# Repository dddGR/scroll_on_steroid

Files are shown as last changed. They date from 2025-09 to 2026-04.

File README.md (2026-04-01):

# Scroll On Steroid

## Table of Contents

- [Overview](#overview)
- [Features](#features)
- [Hardware Requirements](#hardware-requirements)
- [Build guide](#build-guide)
- [Firmware build](#firmware-build)
- [Usage](#usage)
- [Contributing](#contributing)

## Overview

This project is a scroll device that emulates mouse scrolling with enhanced smoothness, utilizing resolution multiplier.

It connects via Bluetooth Low Energy (BLE) and incorporates a touch sensor for user interaction. Users can easily adjust scrolling speed and direction (horizontal/vertical) through a touch button interface.

The device is built on the ESP32-C3/S3 microcontroller and an AS5600 magnetic encoder. This project is developed using the ESP-IDF framework and is entirely written in C.

> ***Only tested on Windows/Linux. Not working on Android. Not yet tested on Mac OS or IOS***

## Features

- **Smooth Scrolling**: Utilizes a resolution multiplier for enhanced scrolling experience.

- **Bluetooth BLE Connectivity**: Wireless connection.

- **Touch Sensor**: Detects user interactions to eliminate false movement.  
User can change scrolling speed or direction via touch interface.

- **Long Battery Life**: Built-in 2000mAh battery for extended use.

- **Easy Assembly**: All components are off-the-shelf parts for straightforward assembly.

## Hardware Requirements

- ESP32-S3/C3 micro sized board
- Magnetic encoder: AS5600
- Touch sensor module: TP223 *(for C3 only)*
- 6809-2RS bearing
- 10345 2000mAh lipo battery
- LX-LBC3 lipo charging module
- SW-200D vibration switch *(for C3 only)*
- MSK12C02 switch *(*optinal)*
- Other components (screw, wire...)

## Build guide

The complete build guide contain in this [Document](https://docs.google.com/presentation/d/1pcG5sJjjT5bdXRbsl7uQMGZX0v1NefzA5OYjOddV2WQ).

## Firmware build

For convenient, a precompiled `firmware_xx.bin` is provided for direct flashing onto the microcontroller (MCU). However, this file contains only the default configuration and is intended for use with the exact hardware specified in the instruction document. For custom configurations, users will need to modify the config, via menuconfig (recommended) or directly in the `user_config.h` file and recompile it themselves.

---------------------------------------------------------------------
The following steps are intended for those who have never used ESP-IDF before. If you are already familiar with ESP-IDF and have existing projects, you can simply take the source files and compile them.

1. **Install the ESP-IDF Framework**

   It is recommended to use Visual Studio Code (VSCode) along with the ESP-IDF extension. Espressif provides detailed documentation on  [installing and using ESP-IDF](https://github.com/espressif/vscode-esp-idf-extension/blob/master/README.md).

2. **Try a Test Build (Optional but Recommended)**

   If you are not familiar with ESP-IDF, it is advisable to build and flash an example sketch from the ESP-IDF example library. This will also help ensure that your board is functioning correctly. Espressif has a very detail [guide](https://docs.espressif.com/projects/vscode-esp-idf-extension/en/latest/startproject.html) for this process.  
   > **Note:** I recommend trying to build the `hello_world` example first, as the `blink` example's default configuration may not work for all board variants.

3. **Create Your ESP-IDF Project**

   Git clone the source code and open it in VSCode (select "Open Folder"). ESP-IDF will notify you if any files are missing; you can ignore this. Open the `ESP-IDF terminal` and type:

   ```bash
   idf.py reconfigure
   ```

   This command will reconfigure your project folder. If any files are missing or settings have not been applied, this will resolve those issues.  
   In fact, whenever I make changes (e.g., editing `CMakeLists` or adding new files or components), I often encounter errors. Usually, cleaning the build and running `reconfigure` again resolves these issues.

   > **Note:** You can open the `ESP-IDF terminal` using a shortcut in the bottom bar or by pressing `Ctrl+Shift+P` and typing `Open ESP-IDF terminal`. This terminal is different from the standard VSCode terminal (usually PowerShell) and includes all the necessary commands, making it much easier to use. If you encounter an error stating that a file is not found or a command is unrecognized, you are likely not using the ESP-IDF terminal.

4. **Select Your MCU Target**

   In the bottom bar, locate the IDF-TARGET box (which will initially display "esp32") and change it to your specific board (S3 or C3). If prompted for a path list, simply choose the first option. Wait for the configuration to complete.

   > **Note:** When you have an IDF terminal open and use the icon in the bottom bar to change the IDF-TARGET, the terminal will not automatically switch to the new board. Any commands run in that terminal will result in a target mismatch error. Close the terminal and open a new one to resolve this issue.

5. **Build and Flash the Project**

   If everything is set up correctly, click the build wrench icon labeled `Build Project` or use the command:

   ```bash
   idf.py build
   ```

   If the build is successful, you can now flash the firmware to your board. Connect your board and set the port to the correct one.

   > If you have only one board connected, it will display only that one.

   Set the flash method to UART (the star icon) and click the flash icon labeled `Flash Device` or use the command:

   ```bash
   idf.py flash
   ```

6. **Complete the Flashing Process**

   Wait for the flashing process to complete, and you are done.

## Usage

- Connect your device via Bluetooth. When prompted for passcode confirmation, simply click OK (or Pair).
- The device features two built-in scroll modes that can be switched with a double press:

> - **Vertical**: Functions like a regular mouse scroll.
> - **Horizontal**: Scrolls in the horizontal direction.

- Additionally, there are two speed settings, fast and slow, which can be changed with a triple press.

> **Note:**
>
> - Only two button functions are implemented for simplicity.
> - Single press is not used for button input to eliminate false button presses during normal usage.
> - Buttons only register when the device is in idle mode. This means that if you want to change settings (e.g., scroll direction) while using the device, you need to lift your finger for about 0.5 seconds before double pressing (or triple pressing).

## Contributing

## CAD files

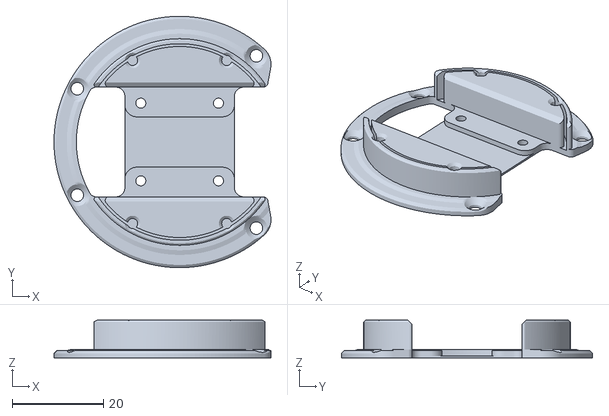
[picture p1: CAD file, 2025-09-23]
hardware/sos_lite_inner_upper.stl
47.5 x 55.0 x 8.30

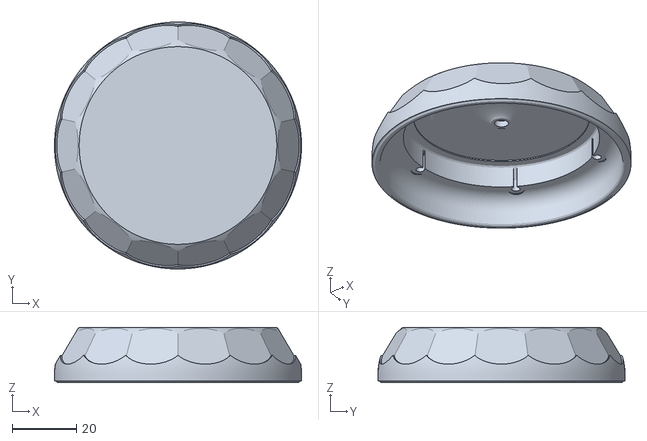
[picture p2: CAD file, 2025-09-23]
hardware/sos_lite_outer_shell.stl
77.0 x 77.0 x 17.2

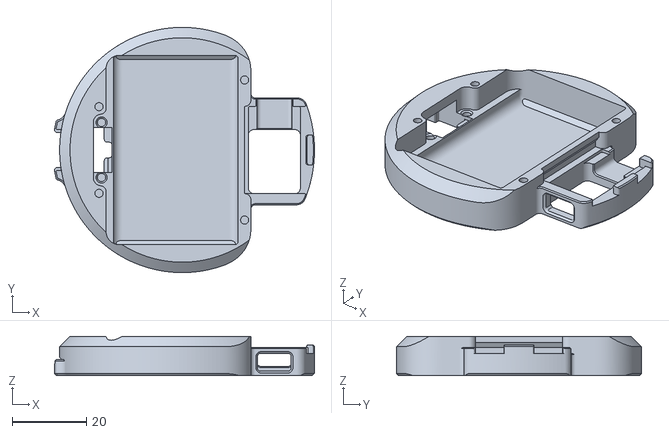
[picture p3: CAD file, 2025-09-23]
hardware/sos_lite_inner_bottom.stl
70.0 x 66.0 x 10.6

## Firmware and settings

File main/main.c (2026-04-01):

#include "HID_bluedroid.h"
#include "driver/gpio.h"
#include "driver/i2c_master.h"
#include "driver/uart.h"
#include "esp_as5600.h"
#include "esp_check.h"
#include "esp_sleep.h"
#include "freertos/FreeRTOS.h"  // IWYU pragma: export
#include "freertos/task.h"      // IWYU pragma: export
#include "sdkconfig.h"
#include "touch_Button.h"
#include "user_Config.h"
#include "user_Config_priv.h"
#include "user_HID_Descriptor.h"

// clang-format off
/* This two variables are store in RTC memory to reuse when device is go to sleep and reboot */
RTC_DATA_ATTR static volatile ScrollSpeedDiv_t g_scroll_div = SPEED_LOW;
RTC_DATA_ATTR static volatile ScrollDirection_t g_scroll_dir = SCROLL_VERTICAL;
// clang-format on

static TaskHandle_t hdl_scroll_task;
/* this is mainly for printing log, can be removed if not needed */
/* ------------------------------- */
static TaskHandle_t hdl_button_task;
#if !CONFIG_USE_TOUCH_BUILTIN
static TaskHandle_t hdl_touch_task;
#endif
/* ------------------------------- */

/* hanle all the events */
static EventGroupHandle_t g_xEventGroup;

#if !CONFIG_USE_TOUCH_BUILTIN
/**
* @brief: The external touch is connected to a GPIO pin and functions as a button. 
* This task is responsible for listening to the input in polling mode and 
* updating the event group bit accordingly. The "lastbits" variable is used 
* to ensure that the bit changes only when necessary. 
*/
void task_TouchScan(void* pvParameter) {
    const char* TAG = "[TOUCH]";
    ESP_LOGI(TAG, "Initializing Touch...");
    ESP_ERROR_CHECK(init_TouchExternal(TAG, CONFIG_PIN_TOUCH_SENSOR));

    EventGroupHandle_t xEventGroup = (EventGroupHandle_t)pvParameter;
    EventBits_t lastbits           = xEventGroupGetBits(xEventGroup);
    EventBits_t currbits;
    TickType_t _xLastWakeTime = xTaskGetTickCount();

    for ( ;; ) {
        currbits = (gpio_get_level(CONFIG_PIN_TOUCH_SENSOR)) ? BUTTON_PRESSED
                                                             : BUTTON_RELEASED;

        if ( currbits & lastbits ) {
            goto end_loop;
        }

        xEventGroupClearBits(xEventGroup, BUTTON_PRESSED | BUTTON_RELEASED);
        lastbits = xEventGroupSetBits(xEventGroup, currbits);

end_loop:
        /* ~100hz */
        xTaskDelayUntil(&_xLastWakeTime, pdMS_TO_TICKS(10));
    }

    /* safe guard */
    vTaskDelete(NULL);
}
#endif

#if CONFIG_USE_TOUCH_BUTTON
/**
* @brief: This task listens for button presses and handles them only when 
* the device is idle and Bluetooth is connected. It has two main functions: 
* 
*   1. If the user double presses the button, it changes the scroll direction 
*    (Horizontal/Vertical).
*   2. If the user triple presses the button, it changes the scroll speed 
*    (High/Low).
* 
* These actions modify a global variable that will be utilized in the 
* {task_MouseScroll}. Single presses are not recognized to prevent 
* false button triggers. 
*/
static void task_Button(void* pvParameter) {
    const char* TAG = "[BUTTON]";

    for ( ;; ) {
        xEventGroupWaitBits(g_xEventGroup,
                            DEVICE_IDLE | BLE_CONNECTED,
                            pdFALSE,
                            pdTRUE,
                            portMAX_DELAY);

        switch ( getButtonPressState(g_xEventGroup, hdl_scroll_task) ) {
            case B_PRESS_2: {
                g_scroll_dir = (g_scroll_dir == SCROLL_HORIZONTAL)
                    ? SCROLL_VERTICAL
                    : SCROLL_HORIZONTAL;
                ESP_LOGI(TAG, "[double pressed] - Change scroll direction.");
            } break;
            case B_PRESS_3: {
                g_scroll_div = (g_scroll_div == SPEED_HIGH) ? SPEED_LOW
                                                            : SPEED_HIGH;
                ESP_LOGI(TAG,
                         "[triple pressed] - Change scroll speed to %s",
                         (g_scroll_div == 1) ? "HIGH" : "LOW");
            } break;
            case B_PRESS_NONE: {
                xEventGroupWaitBits(g_xEventGroup,
                                    DEVICE_ACTIVE,
                                    pdFALSE,
                                    pdTRUE,
                                    portMAX_DELAY);
            } break;
            default:
                break;
        }
    }
    /* safe guard */
    vTaskDelete(NULL);
}
#endif  // CONFIG_USE_TOUCH_BUTTON

static esp_err_t init_Hardware(const char* TAG,
                               i2c_master_bus_handle_t* p_i2c_bus_handle,
                               i2c_master_dev_handle_t* p_i2c_dev_handle,
                               esp_hidd_dev_t** p_hid_dev) {
    ESP_LOGI(TAG, "Initializing BLE.....");
    xEventGroupSetBits(g_xEventGroup, BLE_DISCONNECTED);

    esp_hid_raw_report_map_t ble_report_maps[] = {
        {.data = scrollDescriptor_hiRes,
         .len  = sizeof(scrollDescriptor_hiRes)}};

    const esp_hid_device_config_t ble_hid_config = {
        .vendor_id         = 0x16C0,
        .product_id        = 0x05DF,
        .version           = 0x0100,
        .device_name       = DEVICE_NAME,
        .manufacturer_name = DEVICE_MANUFACTURER,
        .serial_number     = DEVICE_SERIAL,
        .report_maps       = ble_report_maps,
        .report_maps_len   = 1};

    ESP_ERROR_CHECK_WITHOUT_ABORT(hidDevInit(p_hid_dev, &ble_hid_config));

    ESP_LOGI(TAG, "Initializing Magnetic Sensor.....");
    gpio_config_t pin_config = {.pin_bit_mask = BIT(CONFIG_PIN_SENSOR_POWER),
                                .mode         = GPIO_MODE_OUTPUT,
                                .pull_up_en   = GPIO_PULLUP_DISABLE,
                                .pull_down_en = GPIO_PULLDOWN_DISABLE,
                                .intr_type    = GPIO_INTR_DISABLE};
    ESP_RETURN_ON_ERROR(gpio_config(&pin_config),
                        TAG,
                        "failed to configure power pin..");
    ESP_RETURN_ON_ERROR(gpio_set_level(CONFIG_PIN_SENSOR_POWER, 1),
                        TAG,
                        "failed to turn on power..");

    vTaskDelay(pdMS_TO_TICKS(50));

    i2c_master_bus_config_t bus_config = {
        .i2c_port                     = I2C_NUM_0,
        .sda_io_num                   = CONFIG_PIN_SENSOR_SDA,
        .scl_io_num                   = CONFIG_PIN_SENSOR_SCL,
        .clk_source                   = I2C_CLK_SRC_DEFAULT,
        .glitch_ignore_cnt            = 7,
        .flags.enable_internal_pullup = true,
    };

    i2c_device_config_t dev_config = {
        .dev_addr_length = I2C_ADDR_BIT_LEN_7,
        .device_address  = AS5600_DEFAULT_ADDRESS,
        .scl_speed_hz    = 100000UL,
    };

    ESP_RETURN_ON_ERROR(as5600_init(p_i2c_bus_handle,
                                    &bus_config,
                                    p_i2c_dev_handle,
                                    &dev_config),
                        TAG,
                        "failed to init as5600");

    /**
     * @brief: If the SoC has a built-in touch sensor, it will be initialized. 
     * Otherwise, a task will be created to listen for input from the external 
     * touch sensor. The button task will utilize data from the touch sensor 
     * to execute the corresponding button actions.  
     */
#if CONFIG_USE_TOUCH_BUILTIN
    ESP_LOGI(TAG, "Initializing Internal TouchSensor...");
    ESP_ERROR_CHECK(init_TouchBuitin(TAG, CONFIG_TOUCH_PAD_ID, g_xEventGroup));
#else
    xTaskCreatePinnedToCore(&task_TouchScan,
                            "task_TouchScan",
                            2560,
                            (void*)g_xEventGroup,
                            6,
                            &hdl_touch_task,
                            (BaseType_t)APP_CORE_ID);
    vTaskDelay(pdMS_TO_TICKS(100));
#endif  // CONFIG_USE_TOUCH_BUILTIN

#if CONFIG_USE_TOUCH_BUTTON
    xTaskCreatePinnedToCore(&task_Button,
                            "task_Button",
                            3072,
                            NULL,
                            5,
                            &hdl_button_task,
                            (BaseType_t)APP_CORE_ID);
#endif  // CONFIG_USE_TOUCH_BUTTON

    return ESP_OK;
}

/**
* @brief: The {task_MouseScroll} is responsible for reading the encoder and
* sending the scroll data to the HID device via the Bluetooth interface. This
* task also determines the idle and active states of the device. 
*/
static void task_MouseScroll(void* pvParameter) {
    const char* TAG = "[SCROLL]";

    static uint8_t counter_to_idle = 0;
    static uint16_t prev_angle     = 0;
    static uint16_t curr_angle     = 0;
    static EventBits_t bits;
    static i2c_master_bus_handle_t i2c_bus_hdl;
    static i2c_master_dev_handle_t encoder_hdl;
    static esp_hidd_dev_t* p_hid_device;
    ESP_ERROR_CHECK(
        init_Hardware(TAG, &i2c_bus_hdl, &encoder_hdl, &p_hid_device));

    TickType_t xLastWakeTime = xTaskGetTickCount();

    xEventGroupSetBits(g_xEventGroup,
                       DEVICE_IDLE
    /* if no touch interface is used, then device is set to always active */
#if !CONFIG_USE_TOUCH_BUTTON
                           | BUTTON_PRESSED
#endif
    );
    xEventGroupWaitBits(g_xEventGroup,
                        BLE_CONNECTED,
                        pdFALSE,
                        pdFALSE,
                        portMAX_DELAY);

    for ( ;; ) {
        /** @brief:: This is the checkpoint to wait for the device to be active. 
          * If the device is in an active state (or button is pressed) but the
          * "device idle" bit is set, it indicates a transition from idle to active.
          * The next if statement will clear the idle bit while simultaneously 
          * retrieving the current angle of the encoder. This step is crucial 
          * to prevent any changes in angle caused by the magnet spinning 
          * while the device is idle. 
          * 
          * The remainder of the loop involves reading the angle, calculating 
          * the delta, and sending data to the HID device.
          */
        bits = xEventGroupWaitBits(g_xEventGroup,
                                   DEVICE_ACTIVE | BUTTON_PRESSED,
                                   pdFALSE,
                                   pdFALSE,
                                   portMAX_DELAY);
        if ( bits & DEVICE_IDLE ) {
            ESP_LOGI(TAG, "Active state...");
            as5600_get_raw_angle(encoder_hdl, &curr_angle);
            prev_angle = curr_angle;
            xEventGroupClearBits(g_xEventGroup, DEVICE_IDLE);
            xEventGroupSetBits(g_xEventGroup, DEVICE_ACTIVE);
        }

        as5600_get_raw_angle(encoder_hdl, &curr_angle);
        const int16_t delta_angle = (curr_angle
                                     - prev_angle /*  - curr_angle */);

        ESP_LOGD(TAG,
                 "Current angle: %d -- Angle delta: %d",
                 curr_angle,
                 delta_angle);

        /**
         * @brief: When the delta is smaller than the set threshold, it is assumed that 
         * the device is not active. This helps to filter out noise from the encoder. 
         * The "counter_to_idle" variable counts the number of loops in which the 
         * device remains in this state. 
         * 
         * The "prev_angle" is updated at the end of the loop to account for cases 
         * where the user is scrolling at a very slow speed. Over multiple loops, 
         * the accumulated delta angle may eventually trigger scrolling and clear
         * the "counter_to_idle".
         * 
         * However, if the "counter_to_idle" reaches a certain threshold and the 
         * user is not interacting with the device, it will be set to idle state. 
         */
        if ( abs(delta_angle) < CONFIG_SENSOR_NOISE_THRESHOLD ) {
            bits = xEventGroupWaitBits(g_xEventGroup,
                                       BUTTON_PRESSED,
                                       pdFALSE,
                                       pdTRUE,
                                       0);

            if ( ~bits & BUTTON_PRESSED && ++counter_to_idle > 50 ) {
                /* about 500ms with 100hz polling rate */
                ESP_LOGI(TAG, "Entering idle state...");
                xEventGroupClearBits(g_xEventGroup, DEVICE_ACTIVE);
                xEventGroupSetBits(g_xEventGroup, DEVICE_IDLE);
                counter_to_idle = 0;
            }
            goto end_loop;
        } else if ( counter_to_idle > 0 ) {
            counter_to_idle = 0;
        }

        /* in normal use case, the `delta_angle` always stay bellow 100,
         * so a value `128` here to filter out some cases sensor read value
         * jump up and down randomly (noise maybe).  */
        if ( abs(delta_angle) < 128 ) {
            int8_t scroll_val = (int8_t)delta_angle / (int8_t)g_scroll_div;
            switch ( g_scroll_dir ) {
                case SCROLL_VERTICAL: {
                    sendScroll(p_hid_device, -scroll_val, 0);
                } break;
                case SCROLL_HORIZONTAL: {
                    sendScroll(p_hid_device, 0, scroll_val);
                } break;
            }
        }

        prev_angle = curr_angle;

end_loop:
        /* cap at about ~100hz polling rate */
        xTaskDelayUntil(&xLastWakeTime, pdMS_TO_TICKS(10));
    }
}

/* BLE HID CALLBACK */
/* -------------------------------------------------------------------- */
void do_when_ble_hid_connect(void) {
    while ( !hdl_scroll_task ) {
        vTaskDelay(pdMS_TO_TICKS(100));
    }

    xEventGroupClearBits(g_xEventGroup, BLE_CONNECTED | BLE_DISCONNECTED);
    xEventGroupSetBits(g_xEventGroup, BLE_CONNECTED);
    vTaskResume(hdl_scroll_task);
}

void do_when_ble_hid_disconnect(void) {
    if ( !hdl_scroll_task ) {
        goto end;
    }

    vTaskSuspend(hdl_scroll_task);
end:
    xEventGroupClearBits(g_xEventGroup, BLE_CONNECTED | BLE_DISCONNECTED);
    xEventGroupSetBits(g_xEventGroup, BLE_DISCONNECTED);
}

void do_when_ble_hid_stop(void) {
    /* nothing for now */
}

/* -------------------------------------------------------------------- */

static void esp_pre_sleep_config(const char* TAG) {
#if CONFIG_TOUCH_TO_WAKEUP
    ESP_ERROR_CHECK_WITHOUT_ABORT(regTouchWakeup(TAG));
#endif

#if CONFIG_SHAKE_TO_WAKEUP
    const gpio_config_t config = {.pin_bit_mask = BIT(CONFIG_PIN_WAKEUP),
                                  .mode         = GPIO_MODE_INPUT,
                                  .pull_up_en   = GPIO_PULLUP_DISABLE,
                                  .pull_down_en = GPIO_PULLDOWN_ENABLE,
                                  .intr_type    = GPIO_INTR_DISABLE};

    ESP_ERROR_CHECK_WITHOUT_ABORT(gpio_config(&config));
    ESP_ERROR_CHECK_WITHOUT_ABORT(
        esp_sleep_enable_gpio_wakeup_on_hp_periph_powerdown(
            BIT(CONFIG_PIN_WAKEUP),
            ESP_GPIO_WAKEUP_GPIO_HIGH));
#endif

    ESP_ERROR_CHECK_WITHOUT_ABORT(gpio_set_level(CONFIG_PIN_SENSOR_POWER, 0));

    vTaskDelay(pdMS_TO_TICKS(100));
}

/* ===================================================== */
/* MAIN ================================================ */
void app_main(void) {
    const char* MTAG = "[MAIN]";

#if CONFIG_SHAKE_TO_WAKEUP
    ESP_ERROR_CHECK_WITHOUT_ABORT(gpio_reset_pin(CONFIG_PIN_WAKEUP));
#endif
    g_xEventGroup = xEventGroupCreate();

    xTaskCreatePinnedToCore(&task_MouseScroll,
                            "task_MouseScroll",
                            3584,
                            NULL,
                            5,
                            &hdl_scroll_task,
                            (BaseType_t)APP_CORE_ID);

    /* everything will be config in `task_MouseScroll`,
     * main task now will wait 5 seconds (magic number),
     * and then continue to handle sleeping task. */
    vTaskDelay(pdMS_TO_TICKS(1000 * 5));

    /** MAIN also control sleep function */
    EventBits_t bits;
    for ( ;; ) {
#if CONFIG_USE_TOUCH_BUTTON
        /**
         * @note: The main strategy is to wait for the device to enter an idle state, 
         * after which one of two scenarios will occur: 
         * 
         * 1. If BLE is not connected, the device will wait for 30 seconds before 
         *    going to sleep (if BLE remains disconnected).
         * 2. If BLE is connected, the device will wait for 10 minutes (this duration 
         *    can be adjusted in config.h or menuconfig). If the device does not exit 
         *    the idle state during this time, it will go to sleep; otherwise, the 
         *    loop will continue. 
         */
        xEventGroupWaitBits(g_xEventGroup,
                            DEVICE_IDLE,
                            pdFALSE,
                            pdTRUE,
                            portMAX_DELAY);

        bits = xEventGroupWaitBits(
            g_xEventGroup,
            DEVICE_ACTIVE | BLE_DISCONNECTED,
            pdFALSE,
            pdFALSE,
            pdMS_TO_TICKS(1000 * 60 * CONFIG_IDLE_TIME_BEFORE_SLEEP));

        if ( bits & DEVICE_ACTIVE ) {
            continue;
        }

        if ( bits & BLE_DISCONNECTED ) {
            ESP_LOGW(MTAG,
                     "BLE not connected, wait 30 seconds until go to sleep.");
            bits = xEventGroupWaitBits(g_xEventGroup,
                                       DEVICE_ACTIVE | BLE_CONNECTED,
                                       pdFALSE,
                                       pdFALSE,
                                       pdMS_TO_TICKS(1000 * 30));

            if ( bits & BLE_CONNECTED || bits & DEVICE_ACTIVE ) {
                continue;
            }
        }
#else
        /**
         * @note: If a touch sensor is not used, the device is set to remain always active. 
         * In this case, the only condition for determining when to go to sleep is 
         * checking for BLE disconnection. This is maybe not the best strategy. 
         */
        bits = xEventGroupWaitBits(g_xEventGroup,
                                   BLE_DISCONNECTED,
                                   pdFALSE,
                                   pdTRUE,
                                   portMAX_DELAY);

        ESP_LOGW(MTAG, "BLE not connected, wait 30 seconds until go to sleep.");
        bits = xEventGroupWaitBits(g_xEventGroup,
                                   BLE_CONNECTED,
                                   pdFALSE,
                                   pdTRUE,
                                   pdMS_TO_TICKS(1000 * 30));

        if ( bits & BLE_CONNECTED ) {
            continue;
        }
#endif  // CONFIG_USE_TOUCH_BUTTON

        ESP_LOGW(MTAG, "Entering sleep mode.....");
        esp_pre_sleep_config(MTAG);

        /* Some log for testing */
        ESP_LOGW(MTAG, "high watermark %d", uxTaskGetStackHighWaterMark(NULL));
        ESP_LOGW("[SCROLL]",
                 "high watermark %d",
                 uxTaskGetStackHighWaterMark(hdl_scroll_task));
#if CONFIG_USE_TOUCH_BUTTON
    #if !CONFIG_USE_TOUCH_BUILTIN
        ESP_LOGW("[TOUCH]",
                 "high watermark %d",
                 uxTaskGetStackHighWaterMark(hdl_touch_task));
    #endif
        ESP_LOGW("[BUTTON]",
                 "high watermark %d",
                 uxTaskGetStackHighWaterMark(hdl_button_task));
#endif

        uart_wait_tx_idle_polling((uart_port_t)CONFIG_ESP_CONSOLE_UART_NUM);
        esp_deep_sleep_start();
    }
}

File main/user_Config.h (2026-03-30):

#ifndef _USER_CONFIG_H_
#define _USER_CONFIG_H_

#include "sdkconfig.h"
#include "soc/gpio_num.h"  // IWYU pragma: export

#define DEVICE_NAME         CONFIG_DEVICE_NAME
#define DEVICE_MANUFACTURER "DDDGR"
#define DEVICE_SERIAL       "1234567890"

/**
 * @note If you are using configurations defined in the config.h file, 
 * make sure to go to menuconfig and disable the option 
 * {Use menuconfig to set parameters}. If not, this may result in conflicts. 
 */
#if !CONFIG_USE_MENU_CONFIG
    #define CONFIG_IDLE_TIME_BEFORE_SLEEP (10) /* in minutes */

    /* ============================================================== */
    /* ============================================================== */
    #if CONFIG_IDF_TARGET_ESP32C3
        /* MAGNETIC SENSOR */
        /* -------------------------------------------------------------- */
        #define CONFIG_PIN_SENSOR_POWER       (GPIO_NUM_0)
        #define CONFIG_PIN_SENSOR_SDA         (GPIO_NUM_8)
        #define CONFIG_PIN_SENSOR_SCL         (GPIO_NUM_7)
        #define CONFIG_SENSOR_NOISE_THRESHOLD (4)

        /* TOUCH/BUTTON CONFIG */
        /* -------------------------------------------------------------- */
        #define CONFIG_USE_TOUCH_BUTTON (1)
        #define CONFIG_PIN_TOUCH_SENSOR (GPIO_NUM_6)

        /* SLEEP CONFIG */
        /* -------------------------------------------------------------- */
        #define CONFIG_SHAKE_TO_WAKEUP (1)
        #define CONFIG_PIN_WAKEUP      (GPIO_NUM_5)

    #endif  // CONFIG_IDF_TARGET_ESP32C3
    /* ============================================================== */
    /* ============================================================== */
    #if CONFIG_IDF_TARGET_ESP32S3
        /* MAGNETIC SENSOR */
        /* -------------------------------------------------------------- */
        #define CONFIG_PIN_SENSOR_POWER       (GPIO_NUM_12)
        #define CONFIG_PIN_SENSOR_SDA         (GPIO_NUM_10)
        #define CONFIG_PIN_SENSOR_SCL         (GPIO_NUM_11)
        #define CONFIG_SENSOR_NOISE_THRESHOLD (4)

        /* TOUCH/BUTTON CONFIG */
        /* -------------------------------------------------------------- */
        #define CONFIG_USE_TOUCH_BUTTON  (1)
        #define CONFIG_USE_TOUCH_BUILTIN (1)
        #define CONFIG_TOUCH_TO_WAKEUP   (1)

        #if CONFIG_USE_TOUCH_BUILTIN
            #include <soc/touch_sensor_channel.h>
            #define CONFIG_TOUCH_PAD_ID (TOUCH_PAD_GPIO7_CHANNEL)
        #endif

    #endif  // CONFIG_IDF_TARGET_ESP32S3

#endif      // CONFIG_USE_MENU_CONFIG

#endif      // _USER_CONFIG_H_

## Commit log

2025-09-23 3d model sos lite
    [sos_lite_inner_bottom.stl, sos_lite_inner_upper.stl, sos_lite_outer_shell.stl]
2026-03-31 modify -- update i2c master for IDF v6.0
2026-03-31 modify -- limited range of sensor reading angle to filter random noise
    [main.c]
